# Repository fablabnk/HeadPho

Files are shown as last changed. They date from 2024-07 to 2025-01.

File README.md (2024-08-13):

Footprint for NJM4556AV-TE1 can be found here: https://componentsearchengine.com/part-view/NJM4556AV-TE1/New%20Japan%20Radio

# Todo

TODO: take power footprint out of stereo pot footprint (this overlap isn't good!)
DONE: double check schematic against original
TODO: Convert panel holes to NPTH to avoid maximum plated hole size warning (although we won't sent these to fab, so doesn't really matter)

# Inspiration

https://llllllll.co/t/exits-a-4hp-mixer-line-headphone-output-module/52221
https://github.com/forestcaver/Analog-Voice/tree/master/AJH_Headphone_Amp - not kicad
https://www.ericasynths.lv/shop/diy-kits-1/edu-diy-output/
https://busycircuits.com/alm019/
https://nwavguy.blogspot.com/2011/07/o2-headphone-amp.html
https://github.com/russellmcc/eurorack_headphones - kicad
https://github.com/ramphands/Exits - kicad, SMT, op amp available on ali but not common
https://github.com/wntrblm/Speak_to_Me - kicad, headphone amp with inbuilt speaker
https://github.com/tkilla64/eurorack/tree/main/output

# Features

- left and right mono jack 3.5mm inputs - mono sums over when only left plugged
- stereo volume pot
- L and R mono jack 3.5mm outputs (line level)
- stereo 3.5mm jack output

# Circuit explanation

- Audio comes in on 3.5mm mono jacks (L and R)
- The switched input of the R jack takes audio from the L jack, so that when R is not plugged in we get a copy of the L signal in the R output
- Audio level is dropped to line level for L and R channels by two LME49720 audio op amps
- Audio goes out to L and R 3.5mm line level jacks
- A stereo potentiometer attentuates the line level signal for both channels equally
- Two NJM4556 chips drive the headphones
- Audio op amps are needed (LME49720) and an amplifier chip capable of driving (low impedence) headphones

# How It Will Be Used in Our Rack

- two of these will be installed in our rack
- the buff mult can duplicate the final output signal
- we can send this independently to two separate headphone amps

# Notes

- The large amount of 100n decoupling caps is because we need 1 pair per chip, which on the PCB should be placed as close to chip power pins as possible
- I removed the ADP0204 dip switch in the original circuit
    - when switched on, engages an extra 100K resistor between input and output of the opamp on each channel
    - I guess to further attentuate the input signal perhaps to allow for line-level input
    - I will just experiment with different resistor values here instead
- is there any THT alternative to NJM4556AV-TE1? Yes NJM4556AD DIP with same pinout
- symbol pins 7 and 8 on dual pot are just mount points

# Switched plugs explained simply

- Switched plugs have a switch contact/pin
- When there is no plug inserted into the jack the tip contact is touching the switch contact
- This creates a closed circuit between the input signal and the output path through the switch contact
- When a plug is inserted into the jack the signal now flows through the plug instead of the switch contact
- In the case of my headphone amp, I want L input to connect (normal over) to the R when no plug is inserted in the R
- This means that the tip output of the L jack is connected to the switch contact of the R jack

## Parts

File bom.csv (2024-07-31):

Reference | Value | Have? | Datasheet | Footprint | Qty | DNP
C1,C2 | 22p | N 220 |  | Capacitor_THT:C_Disc_D3.0mm_W1.6mm_P2.50mm | 2
C3,C4,C7,C8,C9,C10,C11,C12,C13,C14 | 100n | Y 104 |  | Capacitor_THT:C_Disc_D3.0mm_W1.6mm_P2.50mm | 10
C5,C6 | 22u | N (but use our electrolytic) |  | Capacitor_THT:C_Disc_D3.0mm_W1.6mm_P2.50mm | 2
IC1,IC2 | NJM4556AV-TE1 | N | https://componentsearchengine.com/Datasheets/1/NJM4556AV-TE1.pdf | Package_SO:SSOP-8_5.25x5.24mm_P1.27mm | 2
J1 | IN L | Y |  | PCM_4ms_Jack:EighthInch_PJ398SM | 1
J2 | IN R | Y |  | PCM_4ms_Jack:EighthInch_PJ398SM | 1
J3 | OUT LR 1 | Y |  | PCM_4ms_Jack:EighthInch_Stereo_PJ366ST | 1
J4 | OUT LR 2 | Y |  | PCM_4ms_Jack:EighthInch_Stereo_PJ366ST | 1
J5 | OUT L (LINE) | Y |  | PCM_4ms_Jack:EighthInch_PJ398SM | 1
J6 | Eurorack_Power_10pin_Unshrouded | Y |  | Library:IDC-Header_2x05_P2.54mm_Vertical_Euro_Power_Striped | 1
J7 | OUT R (LINE) | Y |  | PCM_4ms_Jack:EighthInch_PJ398SM | 1
POT1 | 9mm_Dual_50k_DShaft_DualRow | N |  | PCM_4ms_Potentiometer:Potentiometer_Alps_RK09L_Double_Vertical | 1
R1,R2,R3,R4,R5,R6,R7,R8 | 100k | Y |  | Resistor_THT:R_Axial_DIN0207_L6.3mm_D2.5mm_P7.62mm_Horizontal | 8
R9,R10 | 1k | Y |  | Resistor_THT:R_Axial_DIN0207_L6.3mm_D2.5mm_P7.62mm_Horizontal | 2
R11,R12,R13,R14 | 1 | Y |  | Resistor_THT:R_Axial_DIN0207_L6.3mm_D2.5mm_P7.62mm_Horizontal | 4
U1,U2 | LME49720 | N |  | Package_DIP:DIP-8_W7.62mm_Socket | 2

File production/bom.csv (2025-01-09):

Designator | Footprint | Quantity | Value | LCSC Part #
C1, C2 | CP_Radial_D4.0mm_P2.00mm | 2 | 22uF
C10, C13, C14, C3, C4, C5, C6, C7, C8, C9 | C_Disc_D3.0mm_W1.6mm_P2.50mm | 10 | 100n
C11, C12 | C_Disc_D3.0mm_W1.6mm_P2.50mm | 2 | 22p
IC1, IC2 | DIP-8_W7.62mm_Socket | 2 | NJM4556AD
J1 | EighthInch_PJ398SM_3mmNPTH | 1 | IN L
J2 | EighthInch_PJ398SM_3mmNPTH | 1 | IN R
J3 | IDC-Header_2x05_P2.54mm_Vertical_Euro_Power_Striped_ThickerText | 1 | Eurorack_Power_10pin_Unshrouded
J4 | EighthInch_PJ398SM_3mmNPTH | 1 | LINE OUT L
J5 | EighthInch_Stereo_PJ366ST_NPTH | 1 | OUT LR
J6 | EighthInch_PJ398SM_3mmNPTH | 1 | LINE OUT R
POT1 | Dual_9mm_Potentiometer_50K_RK1114GH | 1 | 9mm_Dual_50k_DShaft_DualRow
R1, R10, R2, R3, R4, R5, R6, R9 | R_Axial_DIN0204_L3.6mm_D1.6mm_P1.90mm_Vertical | 8 | 100k
R11, R12, R13, R14 | R_Axial_DIN0204_L3.6mm_D1.6mm_P1.90mm_Vertical | 4 | 1Ω
R7, R8 | R_Axial_DIN0204_L3.6mm_D1.6mm_P1.90mm_Vertical | 2 | 1k
U1, U2 | DIP-8_W7.62mm_Socket | 2 | LME49720

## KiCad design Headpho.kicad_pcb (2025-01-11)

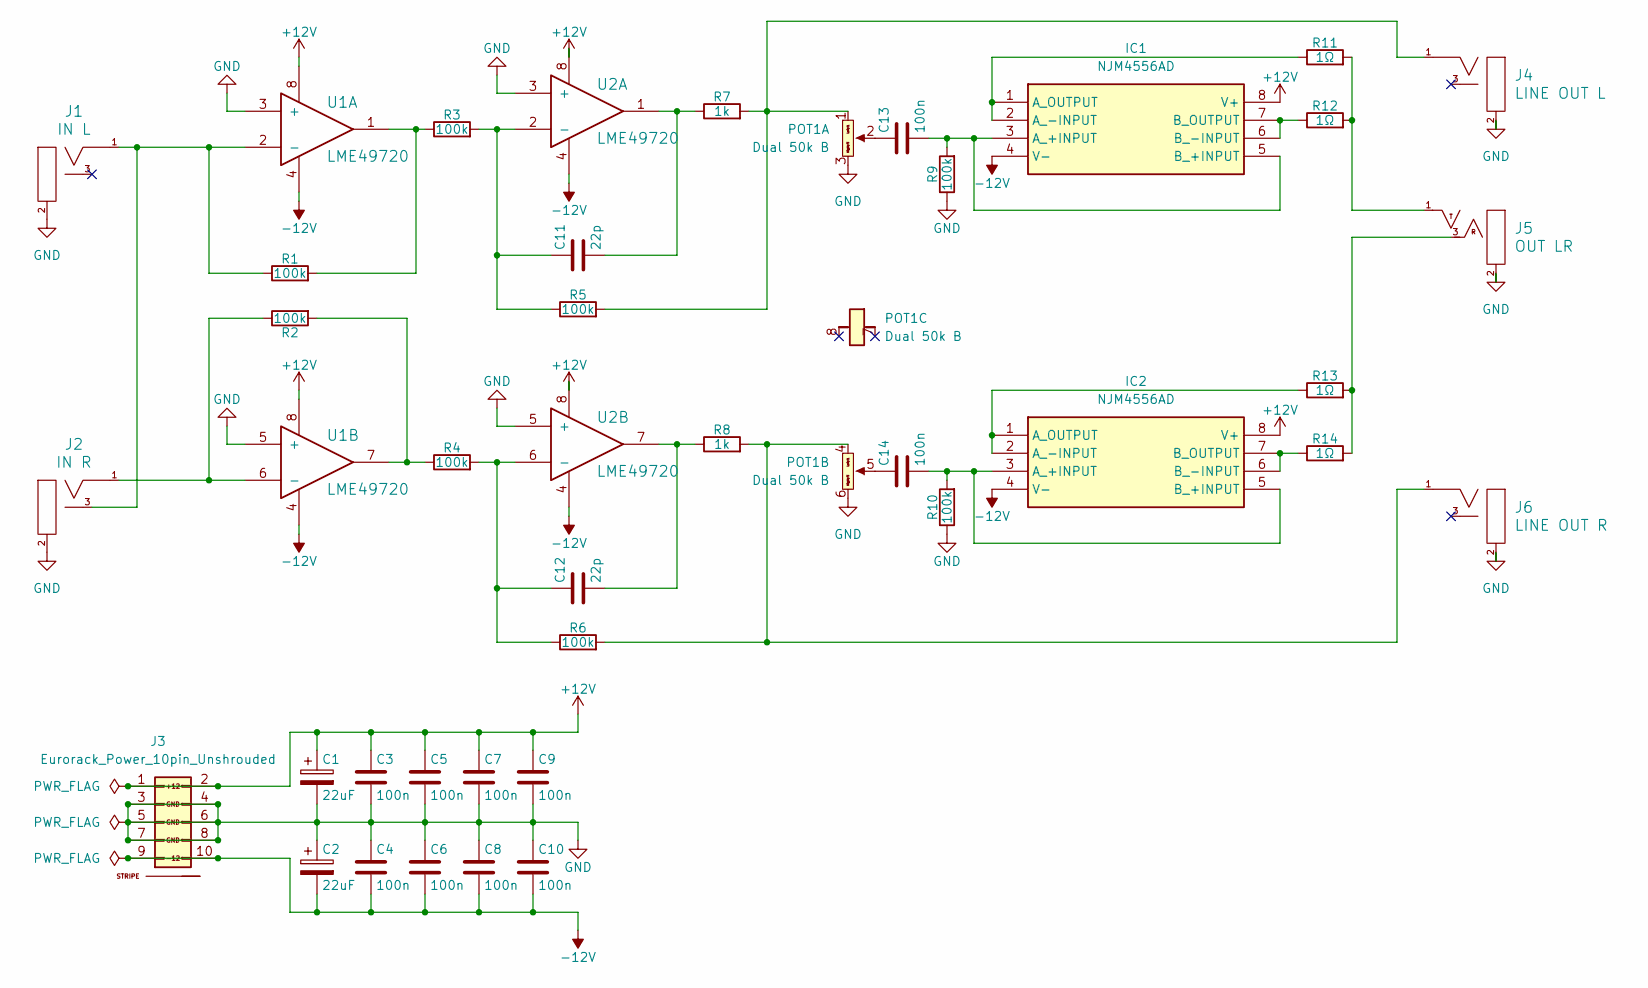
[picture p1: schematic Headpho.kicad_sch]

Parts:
C1, C2: 22uF; CP_Radial_D4.0mm_P2.00mm
C3, C4, C5, C6, C7, C8, C9, C10, C13, C14: 100n; C_Disc_D3.0mm_W1.6mm_P2.50mm
C11, C12: 22p; C_Disc_D3.0mm_W1.6mm_P2.50mm
IC1, IC2: NJM4556AD; DIP-8_W7.62mm_Socket; Manufacturer_Part_Number NJM4556AV-TE1; Mouser Part Number 513-NJM4556AV-TE1
J1: IN L; EighthInch_PJ398SM_3mmNPTH; Part Number WQP-WQP518MA
J2: IN R; EighthInch_PJ398SM_3mmNPTH; Part Number WQP-WQP518MA
J3: Eurorack_Power_10pin_Unshrouded; IDC-Header_2x05_P2.54mm_Vertical_Euro_Power_Striped_Thicker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; Part Number 1-1002FBV0T
J4: LINE OUT L; EighthInch_PJ398SM_3mmNPTH; Part Number WQP-WQP518MA
J5: OUT LR; EighthInch_Stereo_PJ366ST_NPTH; Part Number WQP-WQP518MA
J6: LINE OUT R; EighthInch_PJ398SM_3mmNPTH; Part Number WQP-WQP518MA
POT1: 9mm_Dual_50k_DShaft_DualRow; Dual_9mm_Potentiometer_50K_RK1114GH; Part Number 9M2V5BNB-D-15F-B50K-19WE
R1, R2, R3, R4, R5, R6, R9, R10: 100k; R_Axial_DIN0204_L3.6mm_D1.6mm_P1.90mm_Vertical
R7, R8: 1k; R_Axial_DIN0204_L3.6mm_D1.6mm_P1.90mm_Vertical
R11, R12, R13, R14: 1Ω; R_Axial_DIN0204_L3.6mm_D1.6mm_P1.90mm_Vertical
U1, U2: LME49720; DIP-8_W7.62mm_Socket

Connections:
+12V: C1.1, C3.1, C5.1, C7.1, C9.1, IC1.8 (V+), IC2.8 (V+), J3.1 (+12V), J3.2 (+12V), U1.8, U2.8
-12V: C2.2, C4.2, C6.2, C8.2, C10.2, IC1.4 (V-), IC2.4 (V-), J3.9 (-12V), J3.10 (-12V), U1.4, U2.4
GND: C1.2, C2.1, C3.2, C4.1, C5.2, C6.1, C7.2, C8.1, C9.2, C10.1, J1.2 (SHEILD), J2.2 (SHEILD), J3.3 (GND), J3.4 (GND), J3.5 (GND), J3.6 (GND), J3.7 (GND), J3.8 (GND), J4.2 (SHEILD), J5.2 (SHEILD), J6.2 (SHEILD), POT1.3 (Right), POT1.6 (Right), R9.1, R10.1, U1.3 (+), U1.5 (+), U2.3 (+), U2.5 (+)
unnamed: C11.2, R7.1, U2.1
unnamed: C12.2, R8.1, U2.7
unnamed: C13.2, IC1.3 (A_+INPUT), IC1.5 (B_+INPUT), R9.2
unnamed: IC1.1 (A_OUTPUT), IC1.2 (A_-INPUT), R11.1
unnamed: IC1.6 (B_-INPUT), IC1.7 (B_OUTPUT), R12.1
unnamed: C14.2, IC2.3 (A_+INPUT), IC2.5 (B_+INPUT), R10.2
unnamed: IC2.1 (A_OUTPUT), IC2.2 (A_-INPUT), R13.1
unnamed: IC2.6 (B_-INPUT), IC2.7 (B_OUTPUT), R14.1
unnamed: J1.1 (SIG), J2.3 (SW), R1.1, U1.2 (-)
unnamed: J2.1 (SIG), R2.1, U1.6 (-)
unnamed: J4.1 (SIG), POT1.1 (Left), R5.2, R7.2
unnamed: J5.1 (SIG), R11.2, R12.2
unnamed: J5.3 (SW), R13.2, R14.2
unnamed: J6.1 (SIG), POT1.4 (Left), R6.2, R8.2
unnamed: C13.1, POT1.2 (Center)
unnamed: C14.1, POT1.5 (Center)
unnamed: R1.2, R3.1, U1.1
unnamed: R2.2, R4.1, U1.7
unnamed: C11.1, R3.2, R5.1, U2.2 (-)
unnamed: C12.1, R4.2, R6.1, U2.6 (-)

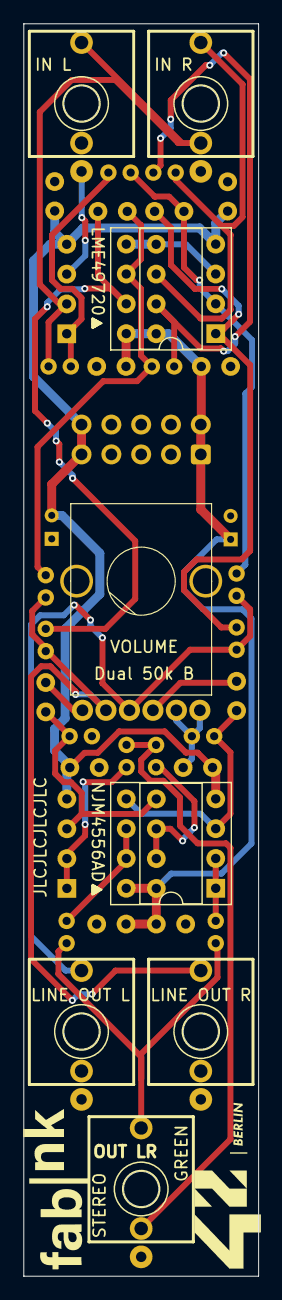
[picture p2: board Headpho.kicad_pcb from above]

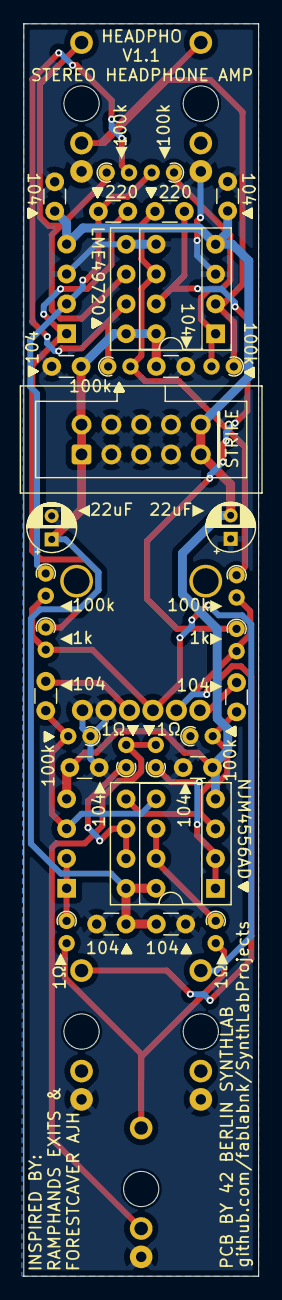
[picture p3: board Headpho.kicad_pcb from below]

Board: 2 copper layers, 20.0 x 106.7 mm, 39 parts (31 on the bottom side), 23 nets.

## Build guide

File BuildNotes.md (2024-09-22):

# V1.0

## Things to pay attention to whilst building
- resistors should all be placed vertically

## Design issues to fix in V1.1
- DONE: solve issue that potentiometer backs onto power connections
- DONE: stereo pot is upside down
- DONE: replace narrow resistor footprints with even more narrow 'true' vertical footprints
- DONE: panel hole for stereo pot should be 9mm dia

## Component issues
- source stereo jack socket

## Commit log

2024-07-31 layed out, routed and completed silkscreen corrections
    [Headpho.kicad_pcb, Headpho.kicad_sch, bom.csv]
2024-08-13 v1.0 almost ready for production
    [Headpho.kicad_pcb, Headpho.kicad_sch, Headpho_Panel.kicad_pcb]
2024-08-15 v1.0 ready for production - fixed some minor silkscreening issues such as adding arrows
    [Headpho.kicad_pcb, bom.csv, designators.csv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]
2024-08-15 shrunk height of board outline to pcb height not panel height
    [Headpho.kicad_pcb]
2024-09-15 added BuildNotes.md. Removed production folder
    [Headpho.kicad_pcb, Headpho.kicad_sch, bom.csv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]
2024-09-22 v1.1 ready for final check
    [Headpho.kicad_pcb, Headpho.kicad_sch, Headpho_Panel.kicad_pcb]
2025-01-09 added production files
    [Headpho.kicad_pcb, bom.csv, designators.csv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]
2025-01-11 fixed silkscreening issues before sending for new boards
    [Headpho.kicad_pcb, Headpho.kicad_sch]
